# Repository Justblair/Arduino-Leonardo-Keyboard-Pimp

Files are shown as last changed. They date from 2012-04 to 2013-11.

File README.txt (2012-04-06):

Arduino Keyboard Pimp

My favourite keyboard is the Cherry G80-3000 mechanical keyboard, but I aim to add additional functions to the device.  On the list is a password manager controlled by RFID.

This project I aim to achieve by using the Arduino Leonardo (well an AVR development board loaded with the Leonardo bootloader).

The project is in it's infancy just now.  It is designed to compile in the Arduino 1.0 environment.  Currently in order to compile for the Leonardo you have to enable it within the arduino-1.0\hardware\arduino\boards.txt file.  

Pinouts and more project details will be added to www.justblair.co.uk as they are finalised.

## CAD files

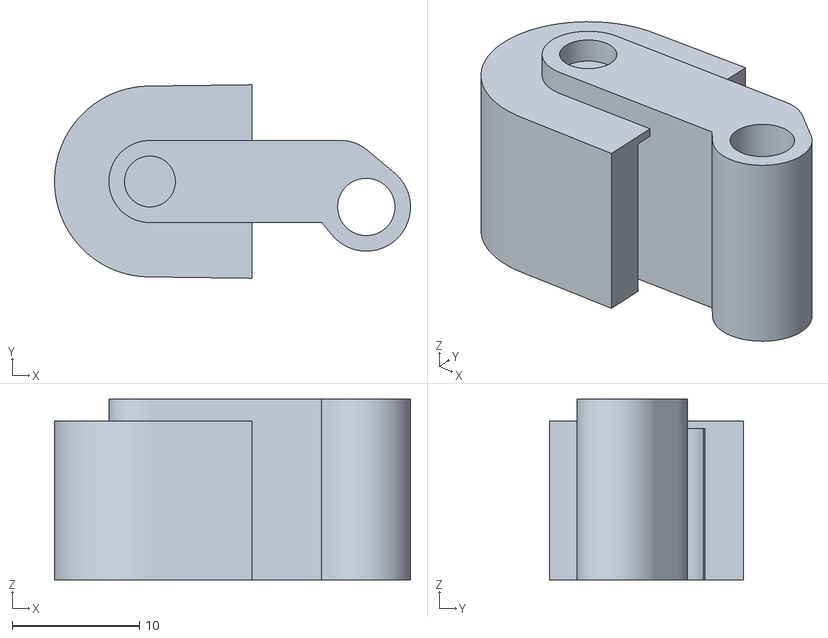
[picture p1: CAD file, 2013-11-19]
foot - Copy.stl
28.0 x 15.2 x 14.2

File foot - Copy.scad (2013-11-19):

																																
bearing_diameter = 		9 ;
bearing_width = 		4 ;
m4_diamter = 			4 ;
main_hole_diameter = 	5 ;
servo_horn_diameter = 	4.5 ;
horn_height = 			3.2 ;
foot_length = 			17  ;
foot_width = 			14.2 ;
layer_height = 			0.3 * 2 ;


$fn =					100 ;
rotate([0,0,180]){
color([0.5,0.5,0.5])
foot();
//mock_bearing();
support();
}
 
e_step_correct = 1.02;
true_filament_width = e_step_correct*.6;
//true_filament_width = .6;

echo(true_filament_width);
hinge_diameter = main_hole_diameter+true_filament_width*4;
servo_outer_diameter = servo_horn_diameter+true_filament_width*4;
 
module foot(){
translate([0,0,foot_width/2]){
	difference(){
		union(){
			hull(){
				translate ([2.0,0]) cylinder (r=m4_diamter/2+true_filament_width*2, h=foot_width, center = true);
				translate([foot_length, 0,0])
					cylinder (r=m4_diamter/2+true_filament_width*2, h=foot_width, center = true);
			} // end hull
			hull(){
				translate ([0,2,0]) 
					cylinder (r=servo_outer_diameter/2, h=  foot_width, center = true);
				translate ([2,0,0])
					cylinder (r=m4_diamter/2+true_filament_width*2, h=foot_width, center = true);
			} //  end hull
		} // end union
		
		translate ([0,2,0])cylinder(r=servo_horn_diameter/2, h=foot_width/2+.1);
		
		translate([0,2,-foot_width/2-.1])

		cylinder(r=servo_horn_diameter/2, h=foot_width/2+.1);
		
		translate([foot_length, 0,0])
			cylinder (r=m4_diamter/2, h=foot_width+.1, center = true);

		translate([foot_length, 0,0])
			cylinder (r=bearing_diameter/2+2, h=bearing_width*2+1.6, center = true);

	} // end difference
	//servo_mount();
	}
}

//servo_mount();

module servo_mount(){
	translate([0,2,foot_width/2-horn_height])
	{                            
		difference(){
		cylinder(r=servo_horn_diameter/2, h=1.2);
		cylinder(r=.5, h=1.3*5);
		}
		cylinder(r=servo_horn_diameter/2, h=.3);
	}        
}

module support(){
translate([0,0,foot_width/2])
	difference(){
		union(){
			hull(){
				cylinder (r=hinge_diameter/2+4, h=foot_width, center = true);
				translate([foot_length, 0,0])
					cylinder (r=bearing_diameter/2-1+4, h=foot_width, center = true);
			} // end hull
		} // end union
		translate([0,0,-foot_width/2+bearing_width+.8])
			hull(){
				cylinder (r=hinge_diameter/2+1, h=foot_width, 	center = true);
			translate([foot_length, 0,0])
				cylinder (r=bearing_diameter/2, h=foot_width, center = true);
			} // end hull
		
		translate([0,0,0])
		cube([18,40,40], center=true);
		translate([-40,-40,bearing_width+.8+layer_height])
		cube([80,80,30], center = false);
	
	} // end difference
			
}

module mock_bearing(){

translate([0,0,foot_width/2]){
	translate([foot_length, 0,-bearing_width-.8])
		{
		color ([1,1,1])
		cylinder (r=4.5 , h=.8);
		translate([0,0,.8])
		color([0.2,0.2,0.2])
		cylinder (r=bearing_diameter/2+1, h=bearing_width, center = false);
		translate([0,0,bearing_width+.8])
		color ([0.2,0.2,0.2])
		cylinder (r=bearing_diameter/2+1, h=bearing_width, center = false);
		translate([0,0,bearing_width*2+.8])
		color ([1,1,1])
		cylinder (r=4.5 , h=.8);
		}
		translate([foot_length, 0,0])
				color ([1,1,1])
		cylinder (r=m4_diamter/2, h=foot_width+.1, center = true);
	}
	}

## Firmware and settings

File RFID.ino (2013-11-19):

// Pimped up keyboard Sketch by Blair Thompson (aka Justblair)
// Project is documented at http://www.justblair.co.uk
// For this sketch to run install the CapacitiveSensor Library
// written by Paul Badger available at
// http://playground.arduino.cc//Main/CapacitiveSensor?from=Main.CapSense
// The project was origionally created using a Cherry G80-3000 Keyboard
// Though other keyboards may be suitable

// Enable DEBUG by uncommenting if you want to see the readings that 
// come from the Capacitive Sensor in a serial console
#define DEBUG  

// Enable Test if you want to test the servo positions.  When the following
// line is uncommented, the switch will set the servos.  In Test mode the
// Servos will be on constantly.  Do not leave the keyboard in Test mode!
// #define TEST

// The following includes invoke the required Libraries
#include <CapacitiveSensor.h>
#include <Servo.h>

// Create the Capacitive Sensor
CapacitiveSensor cs_4_2 = CapacitiveSensor(4,5);        
// 10 mega ohm resistor between pins 4 & 2, pin 2 is sensor pin, add wire, foil

// Create instances of Servo Class
Servo foot_left, foot_right, foot_left2, foot_right2;

// I can put the servos in an object array, This is more a note for later...
// Servo servo[]={foot_left,foot_left2,foot_right, foot_right2 }; 

// Here are some variables
unsigned long last_Time = 0;	// This is used to control the delay before the board drops
int foot_value;					// The foot Value is used to control the current positions of servos
char code[11];					// code is used to store RFID tags for checking against the list
boolean keyboard_state;			// used to record if the keyboard is up or down
boolean prevSwitchState = 0;	// used to check if the switch has been changed recently

// And some usefull constants
const int wait_time = 2000;		// This adds a slight delay before the keyboard lowers.
const int foot_value_up = 130;  // maximum amount of travel of keyboard foot
const int foot_value_down = 20; // minimum amount of travel of keybaord foot
const int capSensitivity = 200; // This sets the threshold for the capacitive sensor

// And this is my RFID tags and their corresponding passwords (not the real passwords obviously)
char* rfidTag[][2] = {
	{"3E00FCC847", "MyWebbyPSWD"},
	{"3D0061DA2D", "MyLoginPSWD"},
	{"3D00492C25", "MyEmailPSWD"},
	{"3E00FCD176", "Etc"        },
};

// I could work this out with sizeoff, but I am too lazy
#define PSWDARRAYSIZE 4

// The setup will only run once
void setup()
{
	Serial.begin(115200);	    // Open a serial Port to the PC

	// Set up the Capacitive sensor
	// turn off auto-calibrate as otherwise the keyboard will 
	// start ignoring me if I am typing for any length of time
	cs_4_2.set_CS_AutocaL_Millis(0xFFFFFFFF);    

	pinMode(7,INPUT);			// Activate the ON/Off switch
	digitalWrite(7,HIGH);		// Activate the internal Pull up resistors
	Keyboard.begin();			// Start the Arduino Keyboard Emulator

	// Little bit of serial printing to say hello
	while (!Serial  && millis() <700){
		;
	}
	Serial.println("Hello");
	Serial.print ("Compiled at ");
	Serial.println(__TIMESTAMP__);

	// The Rfid is connected to the hardware serial port of the Leo
	Serial1.begin(9600);        

	// Set the timer to the current Arduino Time
	last_Time = millis();		
}

// The loop runs forever.
void loop()
{
	// Check the state of the side mounted switch
	boolean switchState = digitalRead(7);

	// Check to see if the switch has changed.  If it has we 
	// will perform a calibration of the capacitive sensor
	// it gradually drifts it's calibration so this gives us 
	// a way to manually calibrate it.
	if (prevSwitchState == 0 && switchState == 1){   
		cs_4_2.reset_CS_AutoCal();
		prevSwitchState = 1;
		Serial.print("Switch on");
		last_Time = millis();
	}
	if (prevSwitchState == 1 && switchState == 0){
		prevSwitchState = 0;
		Serial.println("Switch Off");
	}

#ifndef TEST
	// Providing we are not testing then we do the do
	if (switchState == 1){		// Check the state of the On/Off Switch
		read_capsensor();		// If Switched on, check for humans
	}
	read_RFID();				// Read the RFID to see if there is a chip nearby
#endif


#ifdef TEST
	// If we are testing the sytsem we simply move the 
	// feet up and down depending on the position of the side switch
	Raise_Keyboard(digitalRead(7));  
#endif
}

void read_capsensor(){
	long total_CapacitiveSensor =  cs_4_2.capacitiveSensor(100);

# ifdef DEBUG
	Serial.println(total_CapacitiveSensor);
# endif

	if (total_CapacitiveSensor > capSensitivity){
		last_Time = millis();
		// We check to see if this is a new detection and if so move the legs
		// if not, we do nothing.  We do this so the servos are not constantly
		// in operation 
		if (keyboard_state == 0){
			keyboard_state = 1;
			Raise_Keyboard(1);
		}
	} else if (last_Time + wait_time < millis() && keyboard_state==1){
		// If there is no human present we wait a while and then lower the keyboard
		Raise_Keyboard(0);
		keyboard_state = 0;
	}
}

// This function checks the RFID and if it is correct it writes types the password to the PC.
// The function also sends the RFID ID's to the Serial Console.
void check_password(){
	Serial.print(code);
	Serial.print(": ");

	// The for loop will scan the array for a match to the code we took
	for (int i = 0; i < PSWDARRAYSIZE; i++){
		if (strcmp(code,rfidTag[i][0]) == 0) {
			Keyboard.println (rfidTag[i][1]);
			Serial.println ("OK");
			return;  // We found a match, come out the function now.
		}
	}  // end for

	// We did not find a match in the for loop
	Serial.println("Wrong");  
}  

// This function checks for RFID tags and then runs the check_password function
void read_RFID(){
	if (Serial1.available()){
		if (Serial1.read() == 2){
			Serial1.readBytesUntil (3, code, 10);
			Serial1.flush();
			check_password();
		}
	}
}

// This function moves all of the feet to their correct positions
void Raise_Keyboard(bool foot_state){

	// Lets check the foot state and send the status to the console
	if (foot_state == 1){
		foot_value = foot_value_up;
		Serial.println("Up");
	} else {
		foot_value = foot_value_down;
		Serial.println("Down");
	}

	// We start by attaching the servos that control the feet.
	foot_left.attach(9);  
	foot_left2.attach(11);
	foot_right.attach(10);
	foot_right2.attach(8);

	// We move the feet together.  Because the servo tops are opposing one anther we have to flip
	// the positions around.  
	foot_left.write(foot_value);
	foot_left2.write(map(foot_value,foot_value_down,foot_value_up,foot_value_up,foot_value_down));
	foot_right.write(foot_value);
	foot_right2.write(map(foot_value,foot_value_down,foot_value_up,foot_value_up,foot_value_down));

	// We need to give a short delay to let the servos reach their final position
	delay(250);  

#ifndef TEST
	// Unless we are testing we switch off the feet to preserve the servos.
	foot_left.detach();
	foot_left2.detach();
	foot_right.detach();
	foot_right2.detach();
#endif
}

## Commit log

2012-04-28 Added Capsense commands. The sketch will now check a capacitive sensor along the bottom edge of the keyboard and move the keyboard feet to raise the keyboard. This is tested and working, though it re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
2013-11-19 Added OpenScad and stl files for 3D printed foot
    [foot - Copy.scad, foot - Copy.stl]
